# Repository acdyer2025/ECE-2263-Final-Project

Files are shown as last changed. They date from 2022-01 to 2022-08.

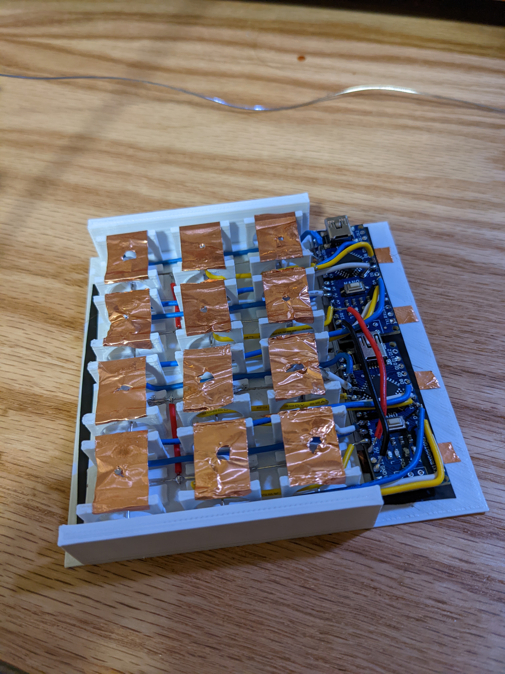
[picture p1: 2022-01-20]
Design Report/Photos of Device/PXL_20211211_002307256.jpg

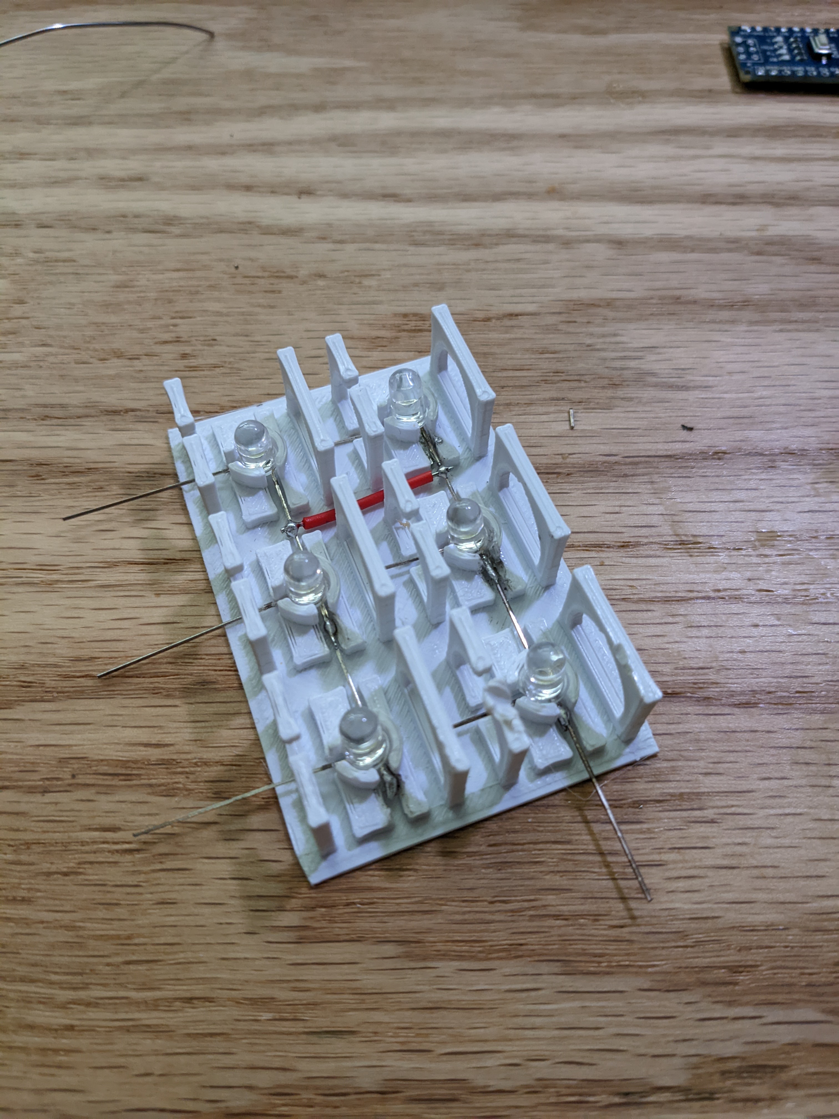
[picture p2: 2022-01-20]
Design Report/Photos of Device/PXL_20211210_202556578.jpg

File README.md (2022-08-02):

# USB-Enabled 4x3 Capacitive Touch Keypad Project Description 

This repository contains all the documents and files for my final project in ECE-2263 Embedded Systems in C. This is an Electrical and Computer Engineering course I took my freshman year of college. The final project was completely up to the student, but it had to incorporate the NUCLEO-STM32F411RE Microcontroller Development Board we had been using all semester.

If you would like an overview of my entire project, I would start by watching the demo video in demonstrationVideo.mp4. I would then read my formal design report found in the Design Report folder as Dyer_FinalProjectDesignReport_v1.pdf. This is a lengthy report detailing exactly what the project is, how it works, and other useful information. That report is my final submission to the instructor for this project. Both files are a bit too large to view directly in GitHub (the report is 48 pages long) so you might have to download them rather than viewing them on GitHub. 

In addition, at the start of this project we created a formal requirements document listing the requirements we expected our project to meet. This can be found in the Requirements Document folder if you wish to see that aspect.

KEYBOARD_HELPER.pdf is the reference for the standard used in HID Keyboard Devices such as this project. I had to reference this when sending the keystroke information from the microcontroller to an attached computer.

The rest of the files contain the source code and .stl files for 3D printing I modeled myself in Fusion360.

NOTE: Most of the code in the STM32F411RE folder is auto generated by the STM32cubeIDE. This vastly speeds up development time but only gets the basic functionality like I/O, serial, debugging, etc. See https://www.st.com/en/development-tools/stm32cubeide.html if you want to learn more.

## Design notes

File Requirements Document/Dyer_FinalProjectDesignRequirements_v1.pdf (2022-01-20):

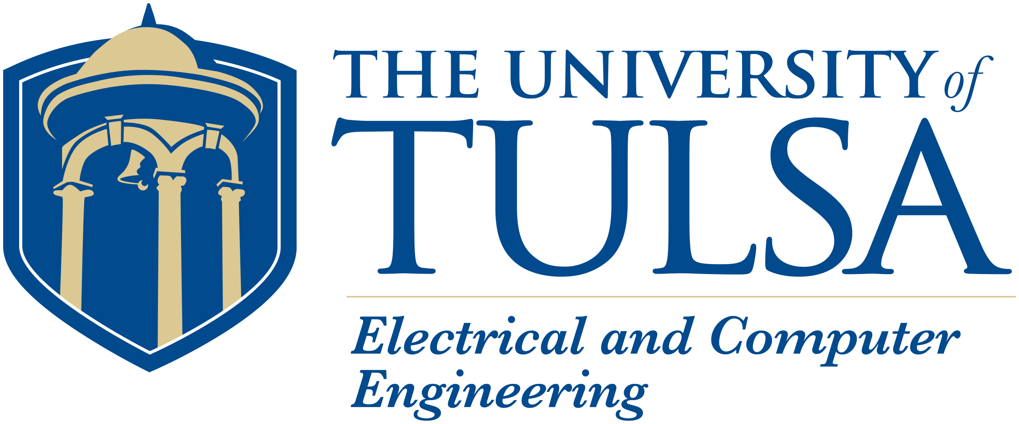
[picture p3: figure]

# USB-Enabled Capacitive Touch Keypad

## Project Requirements

Adam Dyer

November 18, 2021

USB-Enabled Capacitive Touch Keypad | Project Requirements

# Revision History

Date | Version | Author | Description
November 16, 2021 | 1.0 | Adam Dyer | Created File
November 17, 2021 | 1.1 | Adam Dyer | Wrote Report
i | Version 1.1

# Customer Approval

Name | Role | Signature of Approval | Approval Date
Adam Dyer | Engineer | Adam Dyer | November 18, 2021
Nathan Hutchins | Customer | Nathan Hutchins | November 18, 2021
ii | Version 1.1

# Contents

Revision History | i
Customer Approval | ii
Table of Contents | iii
List of Figures | iv
Abstract | 1
Nomenclature | 2
1 Introduction | 3
2 Project Requirements | 5
iii | Version 1.1

# List of Figures

iv | Version 1.1

# Abstract

This report will go over the hardware and software design requirements of the project to create a USB-Enabled Capacitive Touch Keypad. This device will be a 4x3 keypad without any physical buttons on it. Instead, the ”buttons” will be in the form of capacitive touch sensors hidden under the top face of the keypad. Touching the face of the keypad above a touch sensor will act as if you had pressed a physical button located there. This will result in a very sleek and novel device that has no obvious buttons on it yet functions exactly as if it did. There will also be small LED’s hidden under the top face of the keypad that will illuminate when the “button” is pressed, further enhancing its appearance and aesthetic and also functioning as an indicator that the button press was detected. A pair of Arduino Nano’s will control the capacitive sensors themselves and relay that information to a NUCLEO-STM32F411RE Microcontroller Development Board. It will take the information from the Arduino’s and turn them into keystrokes corresponding to which button on the keypad was pressed. The Nucleo will also present itself as a keyboard, and will be able to plug into any computer and act as a connected keyboard. In short, pressing a button on the capacitive sensing keypad will have that character appear on the connected computer as if you had typed that character on the computer itself.

1 | Version 1.1

# Nomenclature

Nucleo | The NUCLEO-STM32F411RE Microcontroller Development Board
LED | Light Emitting Diode
USB | Universal Serial Bus
SPI | Serial Peripheral Interface Communication Protocol
I
2C | Inter-Integrated Circuit Communication Protocol

# Chapter 1

# Introduction

## 1.1 Introduction

Capacitive sensing is a technology that can detect and measure anything that is conductive. Capacitive sensing technology is what makes modern day touchscreens on devices like smartphones, tablets, and ereaders possible. While these types of capacitive sensor touchscreens are quite complicated, the basic principle of a capacitive touch sensor is relatively straightforward. Imagine a piece of metal foil that is connected to a pin of a microcontroller. Because the human body is conductive, when you touch your finger to this piece of metal foil it will change it’s capacitance. Detecting this change in capacitance using the microcontroller allows that piece of metal foil to function as a simple push button.
However, you do not necessarily need to make physical contact with the metal foil. With a sensitive enough setup, you are able to detect the presence of a finger above the metal foil without actually having the finger physically touch the foil. The exact range of detection varies depending on many factors and can range from needing to make physical contact with the sensor to being able to detect a finger from over a foot away. This ability to detect a finger without having the finger make physical contact with the sensor is the basic working principle behind this project.
Another technology that will be implemented in this project is USB On-The-Go. This is a communication protocol that allows devices to communicate with each other over USB and function as both a host and a peripheral. The NUCLEO-STM32F411RE Development Board is USB On-The-Go enabled. This means that it can act both as a host to receive programming instructions from a computer and as a peripheral to send information back to the computer.

## 1.2 Objective

The objective of this project is to combine the capacitive sensing technology and USB-On-The-Go features to create a capacitive touch keypad that will be able to connect to any computer as a keyboard. This means that the capacitive touch keypad will appear to any computer as a connected keyboard, able to send keystroke information to the computer and having those characters appear on the screen as if you typed them yourself.

## 1.3 Customer

Dr. Nathan Hutchins is the intended customer of this project. He is a Professor of Electrical and Computer Engineering at the University of Tulsa, and the instructor of ECE-2263 Embedded Systems in C. This project is designed to fulfill the requirements of the Final Project for ECE-2263. This project will be assessed and graded by Dr. Hutchins and other faculty members.

## 1.4 Design Team

### 1.4.1 Engineering Manager/Lead Engineer

Adam Dyer will be the Engineering Manager and Lead Engineer on this project. He is currently a firstyear undergraduate student at the University of Tulsa majoring in Computer Engineering. He will be the only team member and thus responsible for the entire project, including hardware and software design and construction, assembly, testing, documentation, and presentation.

# Chapter 2

# Project Requirements

## 2.1 Hardware Requirements

### 2.1.1 Keypad Layout

The keypad will be designed as a standard 4x3 keypad, meaning it will have four rows and three columns of buttons. See Figure 2.1 for the layout of the buttons. Each button will have a corresponding touch sensor associated with it.

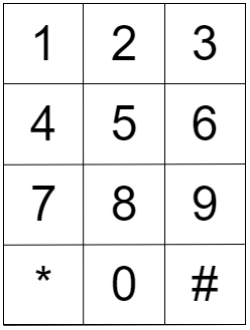
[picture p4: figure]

Figure 2.1: Keypad Layout

### 2.1.2 Enclosure

A key part of what makes this project interesting is the futuristic, sci-fi nature of capacitive touch sensors, since you are essentially pressing a button without actually pressing a button. As such, the overall design of the enclosure will need to be simple and sleek. The keypad itself will be encased in a white 3D-printed enclosure with some type of marking on the top face to indicate the placement of the buttons as shown in Figure 2.1. The top face will be a smooth, solid piece of plastic. The actual metal touch sensors that will detect the button ”press” will be located inside this enclosure and will not be visible on the outside. Essentially, the enclosure will look like a standard keypad without having any of the actual, physical buttons present on it.

### 2.1.3 LED Backlights

Each button will have a small LED mounted to it. This LED will be under the top face of the enclosure, directly above the metal touch sensors. Because the enclosure will be 3D-printed, the light from these LED’s will be able to penetrate this top face. The purpose of these LED’s is to act as indicators for when a button is pressed. When a button is pressed, the LED directly under it will turn on and illuminate that key of the keypad. This will also enhance the futuristic and sleek appearance of the keypad as described in the first part of section 2.1.2. It should be noted that these LED backlights are purely for aesthetic and ease of use, and will have no impact on the actual functionality of the device.

### 2.1.4 Microcontollers

Arduino Nano

Do to time constraints and the complexity of capacitive sensing, a pair of Arduino Nano’s will act as an intermediary between the keypad and the Nucleo. They will only be responsible for controlling the touch sensors under each button and relying that information to the Nucleo. A pair of Arduino Nano’s is used because each touch sensor will require a dedicated analog pin, and two Arduino’s are needed to ensure enough analog pins are available.

Nucleo

The NUCLEO-STM32F411RE Development Board will act as the main microcontroller. It will receive the information about the button presses from the Arduino Nano’s and relay that information to the connected computer using its built in USB-On-The-Go capabilities.

## 2.2 Software Requirements

### 2.2.1 Capacitive Sensing

The software to control and detect the capacitive touch buttons will be written in Arduino C and hosted on the pair of Arduino Nano’s. It should be able to reliably detect the presence of a human finger above each button on the keypad. It needs to be sensitive enough to detect the capacitance of a human finger without it actually touching the metal touch sensors (since those sensors will be hidden under the top face of the enclosure) but robust enough to distinguish each individual button. Basically, it should detect a finger when it is directly above the button, but not detect the finger if it is over an adjacent button. The software also needs to be fast enough to handle multiple buttons being pressed in quick succession.

### 2.2.2 Communication between Arduino’s and the Nucleo

The Arduino’s must be able to communicate with the Nucleo. This will be implemented using either SPI or I²C, and the final determination of which protocol to use will be determined later in the development period depending on which protocol presents itself as the better option. The decision on which protocol to use should have no effect on the final functionality of the device.

### 2.2.3 Nucleo and USB Communication

The software on the Nucleo must be able to receive the SPI or I²C signals coming from the Arduino’s, interpret the signal to determine which button on the keypad was pressed, and relay that information to the Computer using the USB-On-The-Go protocol. Along with this, the Nucleo should present itself to the connected computer as a keyboard so that the computer knows to interpret the information from the Nucleo as keyboard inputs and print the corresponding characters on the computer screen.

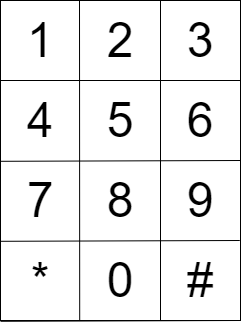
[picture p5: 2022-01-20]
Design Report/Diagrams/keypadLayout.png

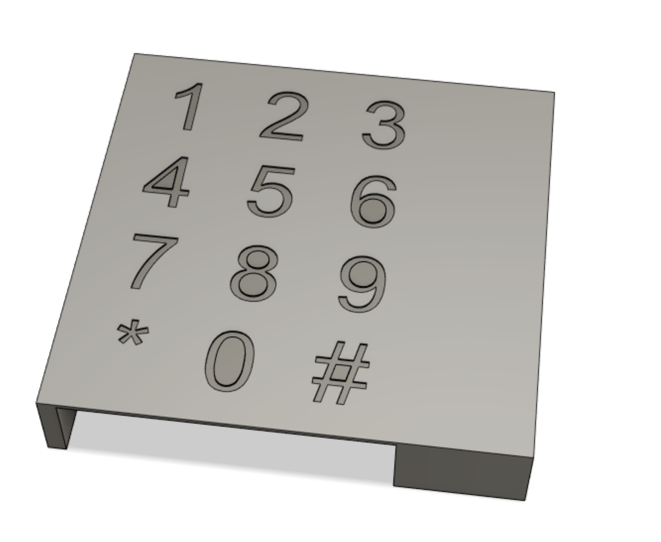
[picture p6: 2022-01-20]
Design Report/Renders of Device/topRender.PNG

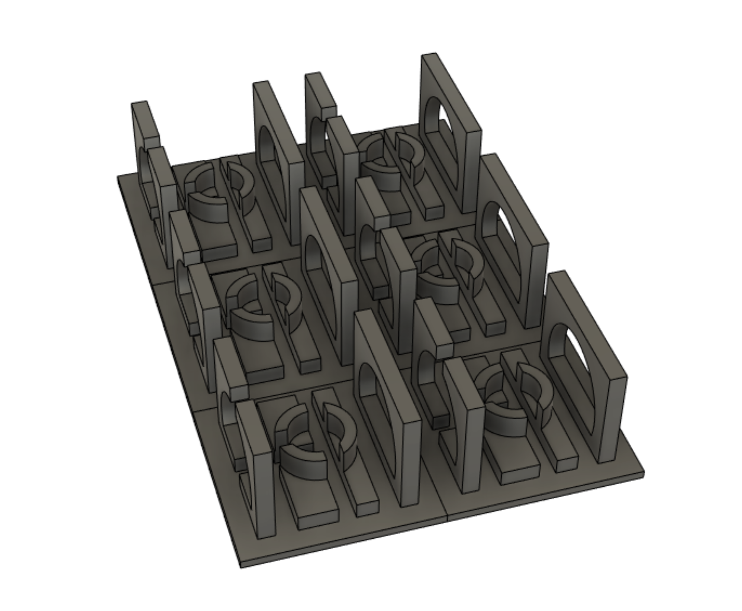
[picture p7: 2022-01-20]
Design Report/Renders of Device/bracketRender.PNG

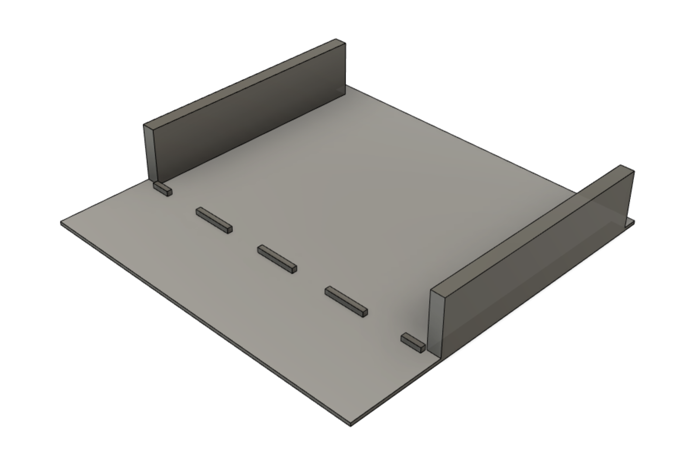
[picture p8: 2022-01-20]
Design Report/Renders of Device/bottomRender.PNG

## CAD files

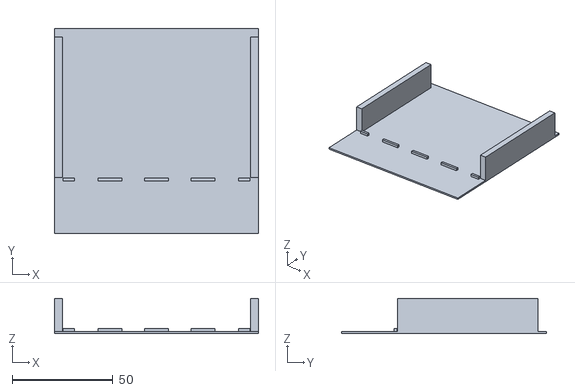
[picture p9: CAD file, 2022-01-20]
STLs/keypadBottom.stl
101.0 x 101.5 x 17.5

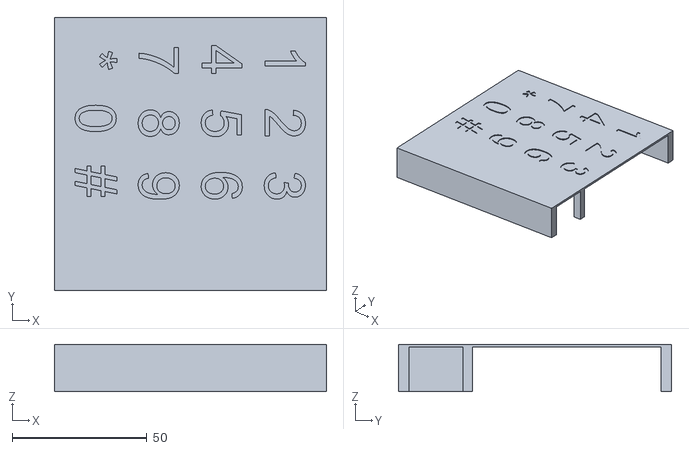
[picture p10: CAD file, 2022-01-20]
STLs/keypadTop.stl
101.0 x 101.5 x 17.5

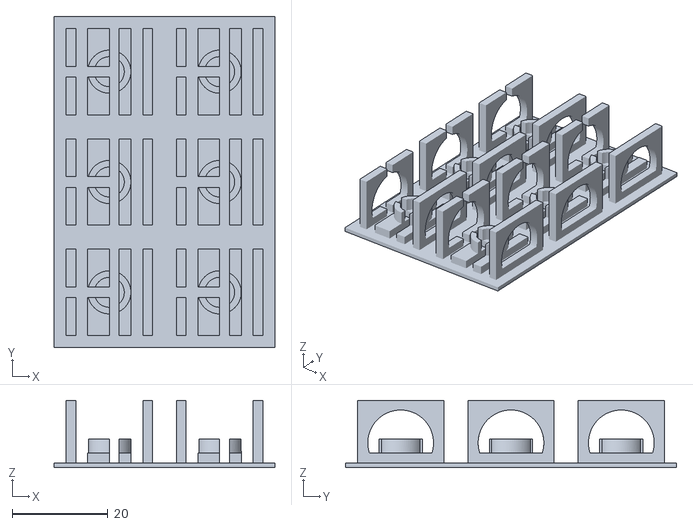
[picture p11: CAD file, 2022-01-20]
STLs/keypadHalfBracket.stl
46.0 x 69.0 x 14.0

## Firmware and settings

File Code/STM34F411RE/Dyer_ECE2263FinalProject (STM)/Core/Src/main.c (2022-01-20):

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
/* Includes ------------------------------------------------------------------*/
#include "main.h"
#include "usb_device.h"

/* USER CODE BEGIN Includes */

#include "string.h"
#include "stdlib.h"
#include "stdio.h"
#include "stdint.h"
#include "usbd_hid.h"

/* USER CODE END Includes */

/* USER CODE BEGIN PTD */

typedef struct
{
	uint8_t MODIFIER;
	uint8_t RESERVED;
	uint8_t KEYCODE1;
	uint8_t KEYCODE2;
	uint8_t KEYCODE3;
	uint8_t KEYCODE4;
	uint8_t KEYCODE5;
	uint8_t KEYCODE6;

} keyboardHID;

keyboardHID keyboard = {0,0,0,0,0,0,0,0};


extern USBD_HandleTypeDef hUsbDeviceFS;

/* USER CODE END PTD */

/* USER CODE BEGIN PD */

#define TIMEOUT_VALUE 50
#define DELAYTIME 250


/* USER CODE END PD */

SPI_HandleTypeDef hspi2;
SPI_HandleTypeDef hspi3;

UART_HandleTypeDef huart2;

/* USER CODE BEGIN PV */

int buttonState = 0;
char buff[20];
char buff2[20];
char newline[] = "\r\n";

/* USER CODE END PV */

void SystemClock_Config(void);
static void MX_GPIO_Init(void);
static void MX_USART2_UART_Init(void);
static void MX_SPI2_Init(void);
static void MX_SPI3_Init(void);
/* USER CODE BEGIN PFP */

void sendKeystroke(int keycode);

/* USER CODE END PFP */

/**
  * @brief  The application entry point.
  * @retval int
  */
int main(void)
{
  /* MCU Configuration--------------------------------------------------------*/

  /* Reset of all peripherals, Initializes the Flash interface and the Systick. */
  HAL_Init();

  /* Configure the system clock */
  SystemClock_Config();

  /* Initialize all configured peripherals */
  MX_GPIO_Init();
  MX_USART2_UART_Init();
  MX_USB_DEVICE_Init();
  MX_SPI2_Init();
  MX_SPI3_Init();
  /* USER CODE BEGIN 2 */


  HAL_Delay(1000);

  /* USER CODE END 2 */

  /* Infinite loop */
  /* USER CODE BEGIN WHILE */
  while (1)
  {
	  HAL_GPIO_WritePin(GPIOC, GPIO_PIN_0, 0);
	  HAL_GPIO_WritePin(GPIOC, GPIO_PIN_1, 0);

	  if(buttonState == 1)
	  {
		  HAL_GPIO_WritePin(GPIOC, GPIO_PIN_0, 1);
		  HAL_GPIO_WritePin(GPIOC, GPIO_PIN_1, 1);
		  HAL_Delay(1000);
		  HAL_GPIO_WritePin(GPIOC, GPIO_PIN_0, 0);
		  HAL_GPIO_WritePin(GPIOC, GPIO_PIN_1, 0);

		  buttonState = 0;
	  }

	  HAL_SPI_Receive(&hspi2, (uint8_t *)buff, 1, TIMEOUT_VALUE);
	  HAL_Delay(50);
	  HAL_SPI_Receive(&hspi3, (uint8_t *)buff2, 1, TIMEOUT_VALUE);

	  //HAL_UART_Transmit(&huart2, (uint8_t *)buff2, strlen(buff2), HAL_MAX_DELAY);
	  //HAL_UART_Transmit(&huart2, (uint8_t *)newline, strlen(newline), HAL_MAX_DELAY);

	  //TOP HALF OF KEYBOARD CHECKS

	  if(buff[0] == '1'){
		  sendKeystroke(0x59);
		  strcpy(buff, "");
		  HAL_Delay(DELAYTIME);
	  }
	  if(buff[0] == '2'){
		  sendKeystroke(0x5A);
		  strcpy(buff, "");
		  HAL_Delay(DELAYTIME);
	  }
	  if(buff[0] == '3'){
		  sendKeystroke(0x5B);
		  strcpy(buff, "");
		  HAL_Delay(DELAYTIME);
	  }
	  if(buff[0] == '4'){
		  sendKeystroke(0x5C);
		  strcpy(buff, "");
		  HAL_Delay(DELAYTIME);
	  }
	  if(buff[0] == '5'){
		  sendKeystroke(0x5D);
		  strcpy(buff, "");
		  HAL_Delay(DELAYTIME);
	  }
	  if(buff[0] == '6'){
		  sendKeystroke(0x5E);
		  strcpy(buff, "");
		  HAL_Delay(DELAYTIME);
	  }

	  //BOTTOM HALF OF KEYPAD CHECKS

	  if(buff2[0] == '7'){
		  sendKeystroke(0x5F);
		  strcpy(buff2, "");
		  HAL_Delay(DELAYTIME);
	  }
	  if(buff2[0] == '8'){
		  sendKeystroke(0x60);
		  strcpy(buff2, "");
		  HAL_Delay(DELAYTIME);
	  }
	  if(buff2[0] == '9'){
		  sendKeystroke(0x61);
		  strcpy(buff2, "");
		  HAL_Delay(DELAYTIME);
	  }
	  if(buff2[0] == '0'){
		  sendKeystroke(0x62);
		  strcpy(buff2, "");
		  HAL_Delay(DELAYTIME);
	  }
	  if(buff2[0] == '*'){
		  sendKeystroke(0x55);
		  strcpy(buff2, "");
		  HAL_Delay(DELAYTIME);
	  }
	  if(buff2[0] == '#'){		//this one is different because some computers do not support the keypad # code so I had to use left shift and 3

		  keyboard.MODIFIER = 0x02;
		  keyboard.KEYCODE1 = 0x20;
		  USBD_HID_SendReport(&hUsbDeviceFS, (uint8_t*)&keyboard, sizeof(keyboard));
		  HAL_Delay(50);

		  keyboard.MODIFIER = 0x00;
		  keyboard.KEYCODE1 = 0x00;
		  USBD_HID_SendReport(&hUsbDeviceFS, (uint8_t*)&keyboard, sizeof(keyboard));
		  HAL_Delay(50);

		  strcpy(buff2, "");
		  HAL_Delay(DELAYTIME);
	  }
	  else{
		  strcpy(buff, "");
		  strcpy(buff2, "");
	  }


    /* USER CODE END WHILE */

    /* USER CODE BEGIN 3 */
  }
  /* USER CODE END 3 */
}

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
/* USER CODE BEGIN 4 */

void sendKeystroke(int keycode)
{
	keyboard.KEYCODE1 = keycode;
	USBD_HID_SendReport(&hUsbDeviceFS, (uint8_t*)&keyboard, sizeof(keyboard));
	HAL_Delay(50);

	keyboard.KEYCODE1 = 0x00;
	USBD_HID_SendReport(&hUsbDeviceFS, (uint8_t*)&keyboard, sizeof(keyboard));
	HAL_Delay(50);
}




/* USER CODE END 4 */
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


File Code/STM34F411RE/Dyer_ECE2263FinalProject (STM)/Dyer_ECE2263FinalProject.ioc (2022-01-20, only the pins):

Mcu.UserName=STM32F411RETx
PA0-WKUP.Signal=USART2_CTS
PA1.Signal=USART2_RTS
PA11.Signal=USB_OTG_FS_DM
PA12.Signal=USB_OTG_FS_DP
PA13.GPIO_Label=TMS
PA13.Signal=SYS_JTMS-SWDIO
PA14.GPIO_Label=TCK
PA14.Signal=SYS_JTCK-SWCLK
PA2.GPIO_Label=USART_TX
PA2.Signal=USART2_TX
PA3.GPIO_Label=USART_RX
PA3.Signal=USART2_RX
PA5.GPIO_Label=LD2 [Green Led]
PA5.Signal=GPIO_Output
PB10.Signal=SPI2_SCK
PB12.Signal=SPI3_SCK
PB3.GPIO_Label=SWO
PB3.Signal=SYS_JTDO-SWO
PC0.Signal=GPIO_Output
PC1.Signal=GPIO_Output
PC12.Signal=SPI3_MOSI
PC13-ANTI_TAMP.GPIO_Label=B1 [Blue PushButton]
PC13-ANTI_TAMP.Signal=GPXTI13
PC14-OSC32_IN.Signal=RCC_OSC32_IN
PC15-OSC32_OUT.Signal=RCC_OSC32_OUT
PC3.Signal=SPI2_MOSI

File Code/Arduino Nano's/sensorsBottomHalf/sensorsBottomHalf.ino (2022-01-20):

#include <ADCTouch.h>
#include <SPI.h>

#define on LOW
#define off HIGH
#define SAMPLES 50
#define CALIBRATE_SAMPLES 100
#define DELAYTIME 0

#define but1 A0
#define but2 A2
#define but3 A1
#define but4 A5
#define but5 A3
#define but6 A4

#define but1LED 7
#define but2LED 5
#define but3LED 6
#define but4LED 4
#define but5LED 3
#define but6LED 2

#define calibrateSignalPin 9

int buts[6] = {but1, but2, but3, but4, but5, but6};
int refs[6] = {0, 0, 0, 0, 0, 0};
int values[6] = {0, 0, 0, 0, 0, 0};
int thresholds[6] = {4, 7, 8, 5, 7, 5};
int leds[6] = {but1LED, but2LED, but3LED, but4LED, but5LED, but6LED};

char sendValues[6] = {'7', '8', '9', '*', '0', '#'};

int counter = 0;
int oneTimeCounter = 0;
int calibrateFlag = 0;

void setup() {
  
  Serial.begin(9600);
  SPI.begin();

  for(int i = 0; i<6; i++)
  {
    pinMode(leds[i], OUTPUT);
    digitalWrite(leds[i], off);
  }
  pinMode(calibrateSignalPin, INPUT);

  //calibrate();
  delay(1000);

}

void loop() {

  if(counter == 1000 || oneTimeCounter == 10)
  {
    getRefs();
    counter = 0;
  }

  calibrateFlag = digitalRead(calibrateSignalPin);
  if(calibrateFlag == 1)
  {
    calibrate();
  }
 
  for(int i = 0; i<6; i++)
  {
    values[i] = (ADCTouch.read(buts[i], SAMPLES) - refs[i]); 
    Serial.print(values[i]);
    Serial.print("   ");
    if(values[i] > thresholds[i])
    {
      digitalWrite(leds[i], on);
      SPI.transfer(sendValues[i]);
    }
    else
    {
      digitalWrite(leds[i], off);
    }
    delay(DELAYTIME);
  }
  
  Serial.println("");
  counter++;
  oneTimeCounter++;
}

void getRefs()
{
 delay(100);
 for(int i = 0; i<6; i++)
 {
   refs[i] = ADCTouch.read(buts[i], 200);
   delay(DELAYTIME);
 }
 delay(100);
}

void calibrate()
{
  for(int i = 0; i<6; i++)
  {
    digitalWrite(leds[i], on);
  }
  delay(2000);
  
  for(int i = 0; i<6; i++)
  {
    digitalWrite(leds[i], off);
  }
  delay(1000);
  
  for(int i = 0; i<6; i++)
  {
    digitalWrite(leds[i], on);
    delay(2000);
    getRefs();
    digitalWrite(leds[i], off);
    delay(2000);
  
    for(int j = 0; j<CALIBRATE_SAMPLES; j++)
    {
      values[i] += (ADCTouch.read(buts[i], SAMPLES) - refs[i]);
    }
    values[i] = values[i]/CALIBRATE_SAMPLES;
    delay(500);
  }
  thresholds[0] = values[0] - 3;
  thresholds[1] = values[1] - 3;
  thresholds[2] = values[2] - 2;
  thresholds[3] = values[3] - 1;
  thresholds[4] = values[4] - 1;
  thresholds[5] = values[5] - 2;

  Serial.println("Threshold Values");
  for(int i = 0; i<6; i++)
  {
    Serial.print(thresholds[i]);
    Serial.print("   ");
  }
  Serial.println("");
  
  for(int i = 0; i<6; i++)
  {
    digitalWrite(leds[i], on);
  }
  delay(2000);
  
  for(int i = 0; i<6; i++)
  {
    digitalWrite(leds[i], off);
  }
  delay(1000);
  getRefs();
  delay(1000);
}

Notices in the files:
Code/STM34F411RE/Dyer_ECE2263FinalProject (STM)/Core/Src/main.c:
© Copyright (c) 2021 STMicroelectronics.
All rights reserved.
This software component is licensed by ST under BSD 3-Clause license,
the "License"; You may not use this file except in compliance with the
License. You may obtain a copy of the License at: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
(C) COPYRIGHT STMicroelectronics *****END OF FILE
